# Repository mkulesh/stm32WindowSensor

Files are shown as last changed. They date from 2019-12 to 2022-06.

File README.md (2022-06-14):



# stm32WindowSensor

*RF window sensors: STM32L + RFM69 + Android*

This is a DIY windows monitorig system that consist of:
- A window sensor based on STM32L051 MCU and RFM69 RF module. The PCB is developed in EagleCad, firmware written in C++ using System Workbench for STM32
- A server unit also based on STM32L051 MCU and RFM69 RF module
- A server software module (Java) that reads data from server unit and forwards it to the mobile app
- A mobile app for Android written in Java

## Window Sensor
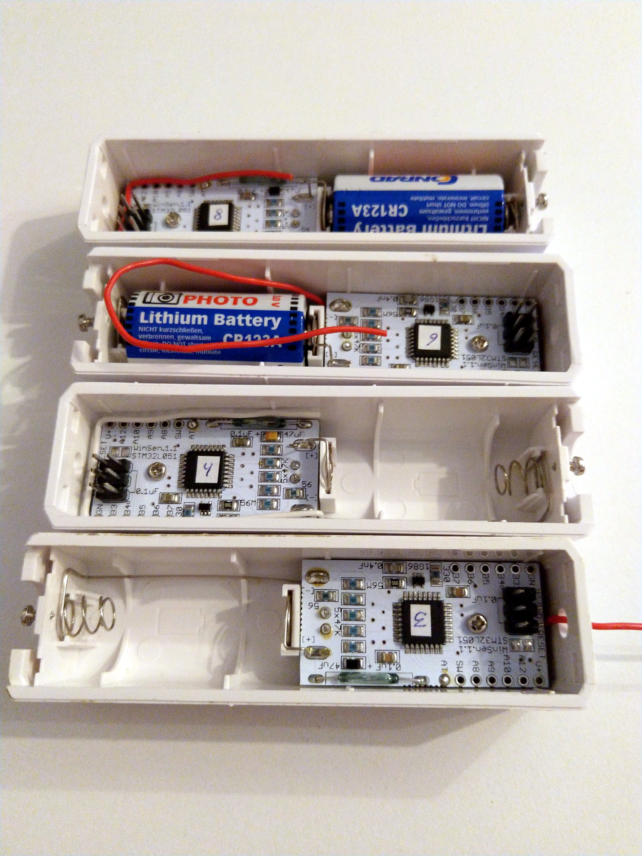
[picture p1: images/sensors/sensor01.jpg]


## Server Unit


## Android App
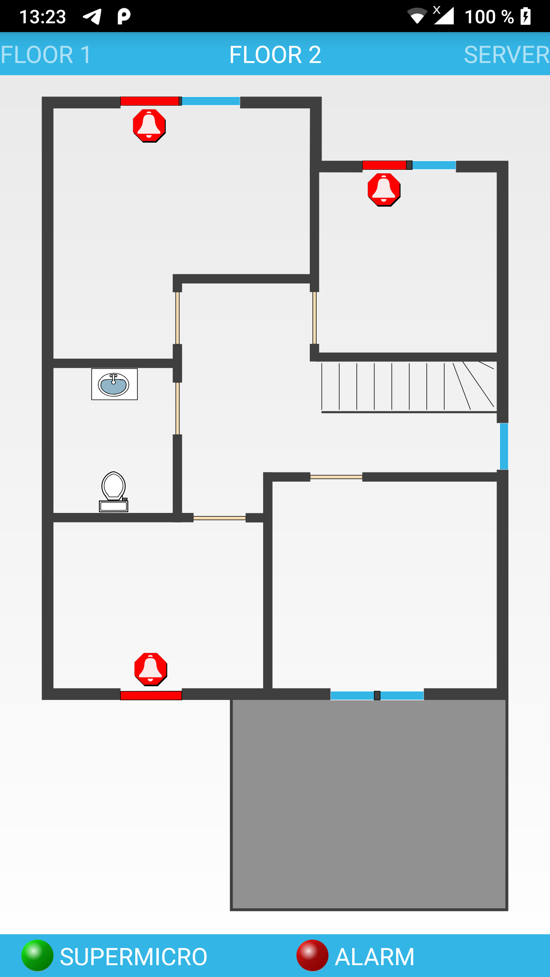
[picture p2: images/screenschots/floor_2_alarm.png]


## License

This software is published under the *GNU General Public License, Version 3*

Copyright © 2018-2019 by Mikhail Kulesh

This program is free software: you can redistribute it and/or modify it under the terms of the GNU General Public License as
published by the Free Software Foundation, either version 3 of the License, or (at your option) any later version.

This program is distributed in the hope that it will be useful, but WITHOUT ANY WARRANTY; without even the implied warranty
of MERCHANTABILITY or FITNESS FOR A PARTICULAR PURPOSE.  See the GNU General Public License for more details. You should have
received a copy of the GNU General Public License along with this program.

If not, see [www.gnu.org/licenses](https://www.gnu.org/licenses).

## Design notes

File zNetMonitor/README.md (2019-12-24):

How to build and install server module and Android app:

1. On the build host:
- Install and setup AndroidStudio, import zNetMonitor project
- In the terminal, go to zNetMonitor directory and enter 

> ./gradlew buildServer

- File znet-server-X.X.jar appears in the _release_ directory. 
- Build the app from AndroidStudio
- File znet-monitor-1.1-release.apk appears in the _release_ directory
- Attach Android device via USB and install the app

> adb install release/znet-monitor-1.1-release.apk

2. On the CentOS 7 server:
- Ensure that the "FT232 Serial" exists and loaded:

> lsusb

> Bus 001 Device 091: ID 0403:6001 Future Technology Devices International, Ltd FT232 Serial (UART) IC

- Add port 5017 fo the firewall:

> firewall-cmd --zone=internal --add-port=5017/tcp --permanent

> firewall-cmd --reload

> firewall-cmd --list-all-zones 
  
- Copy znet ADE (release directory) that includes: znet-server-X.X.jar, znet.cfg, librxtxSerial.so library, startup.sh file
- As root, run startup.sh

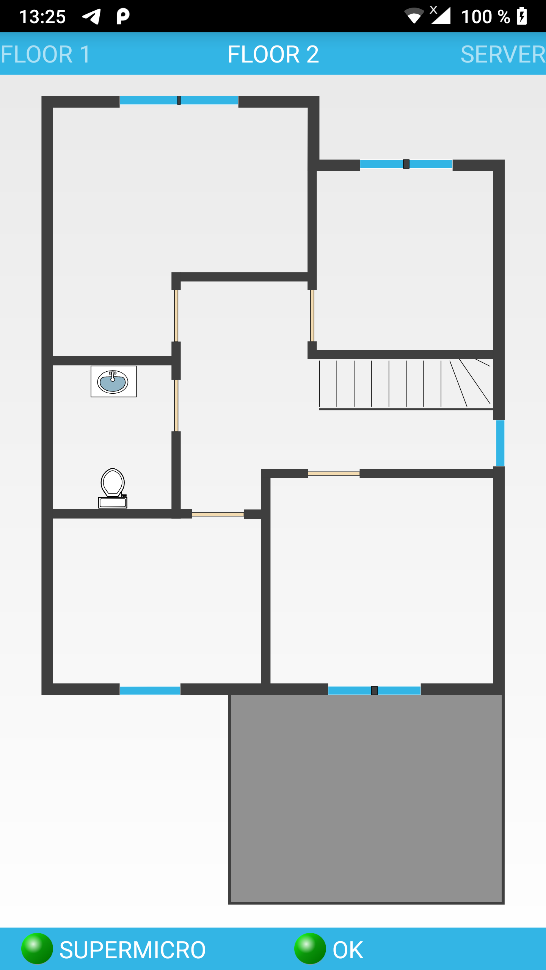
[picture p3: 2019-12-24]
images/screenschots/floor_2_ok.png

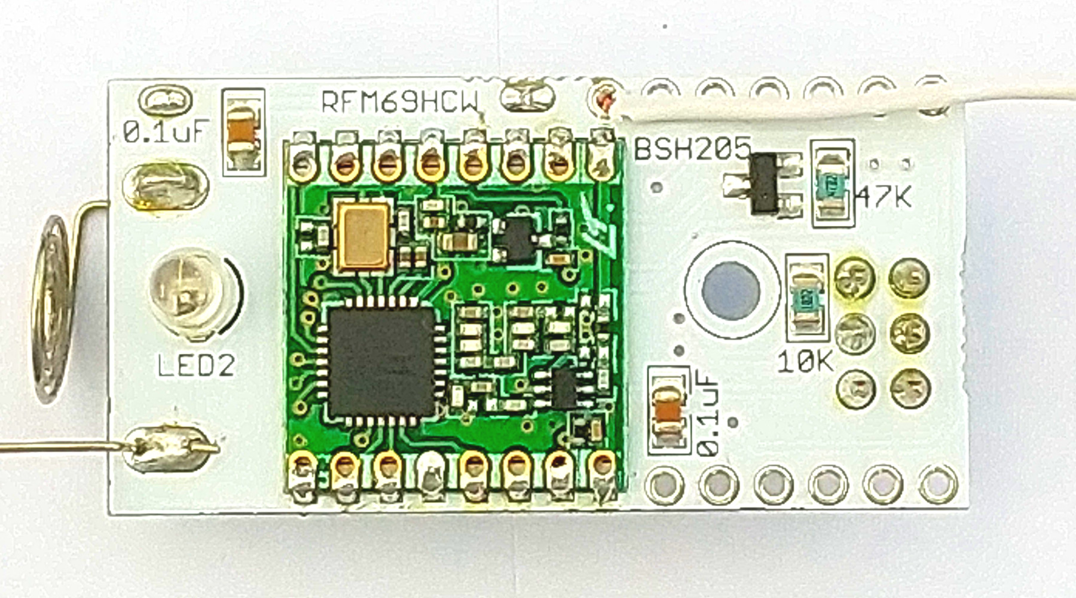
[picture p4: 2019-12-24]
images/sensors/sensor07.jpg

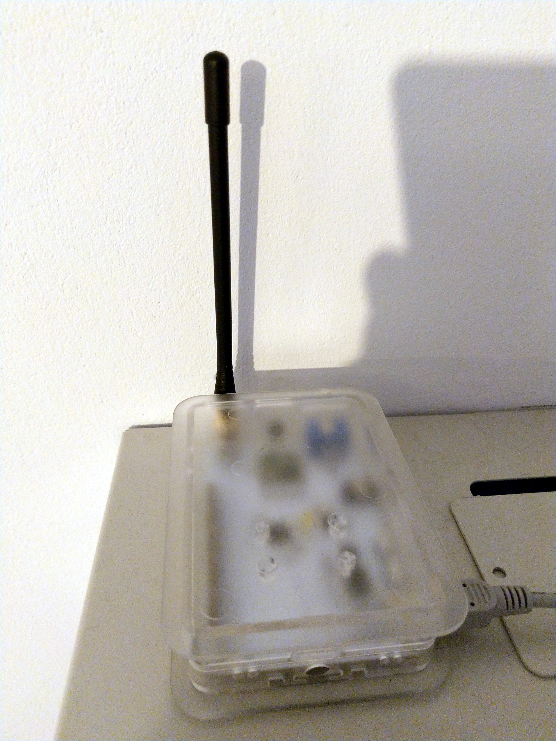
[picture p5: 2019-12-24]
images/server/server02.jpg

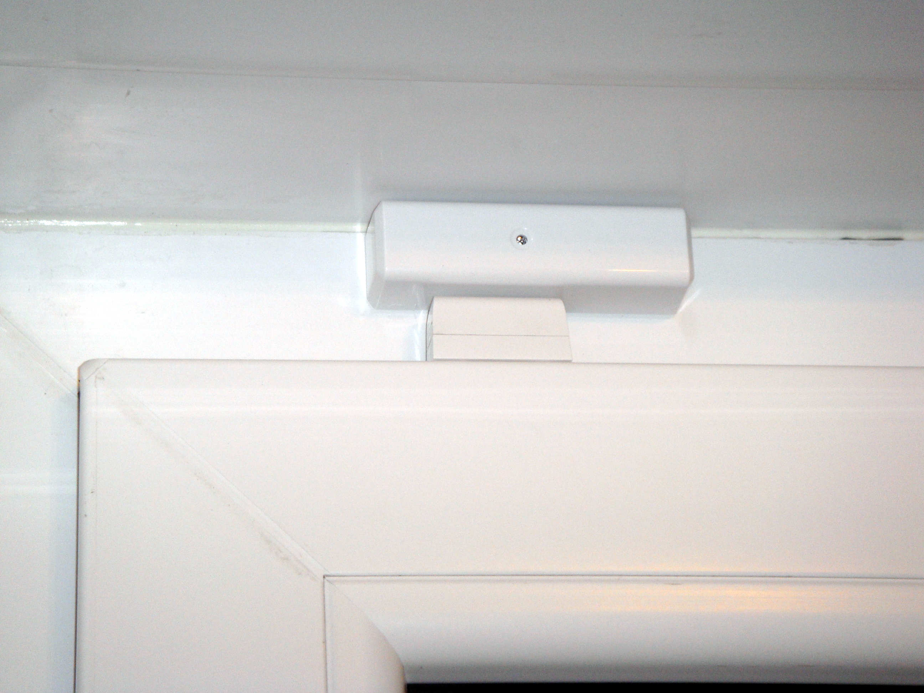
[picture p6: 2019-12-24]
images/sensors/sensor05.jpg

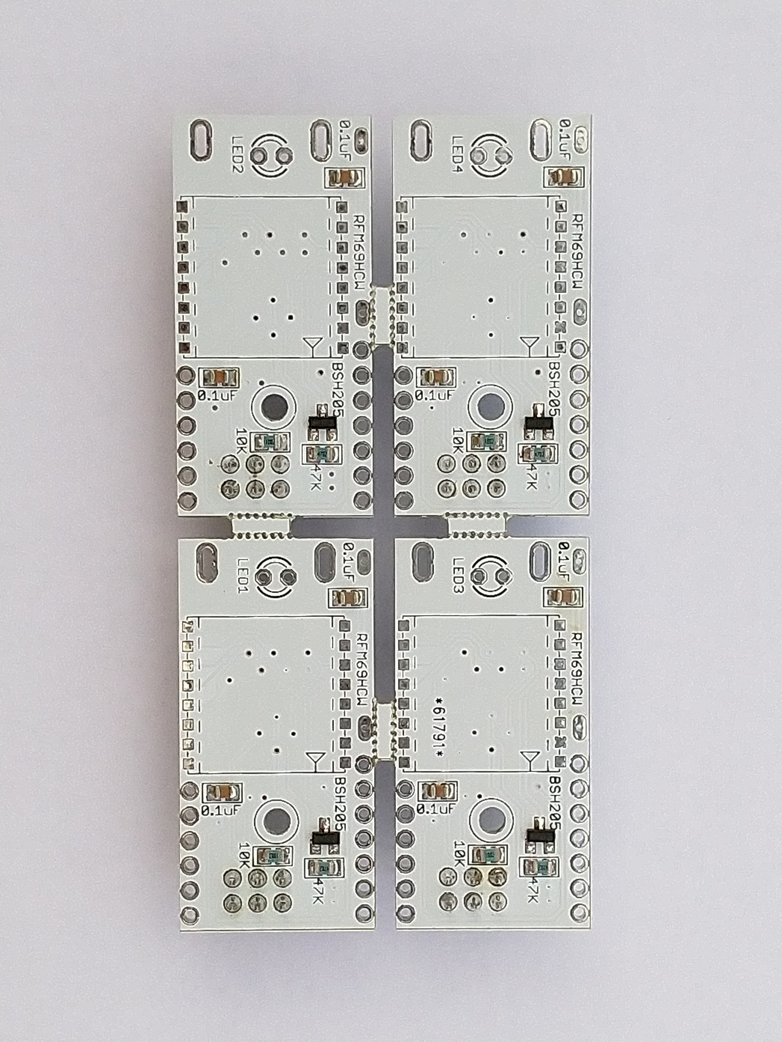
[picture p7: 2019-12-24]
images/pcb/pcb_buttom.jpg

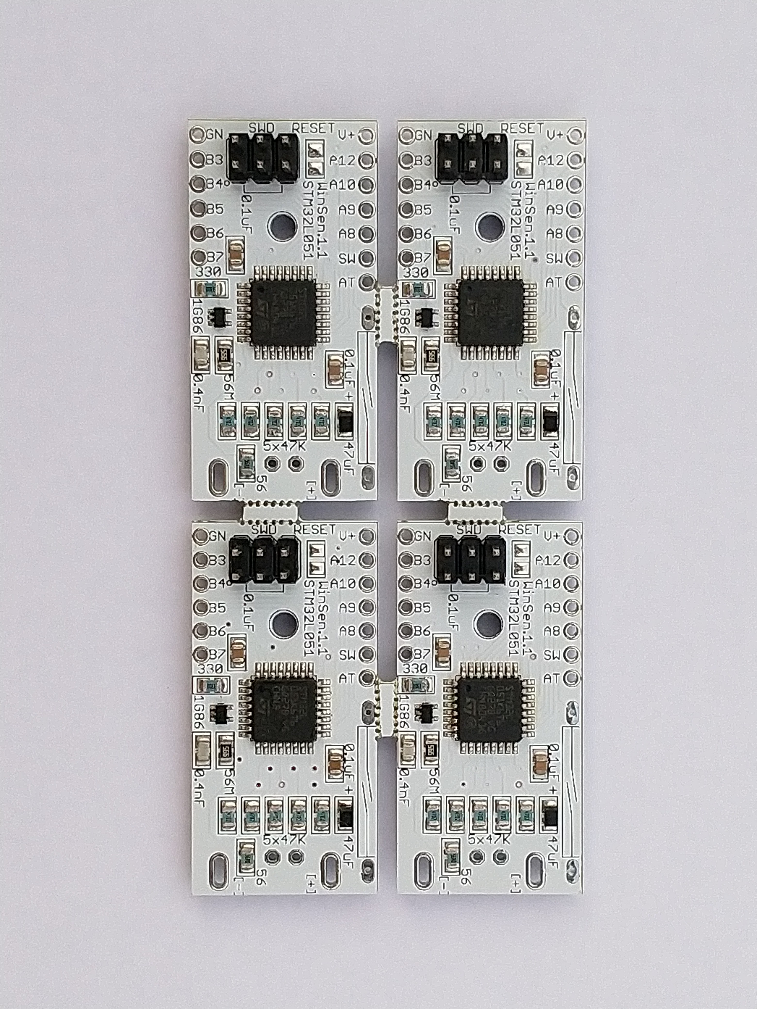
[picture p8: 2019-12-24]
images/pcb/pcb_top.jpg

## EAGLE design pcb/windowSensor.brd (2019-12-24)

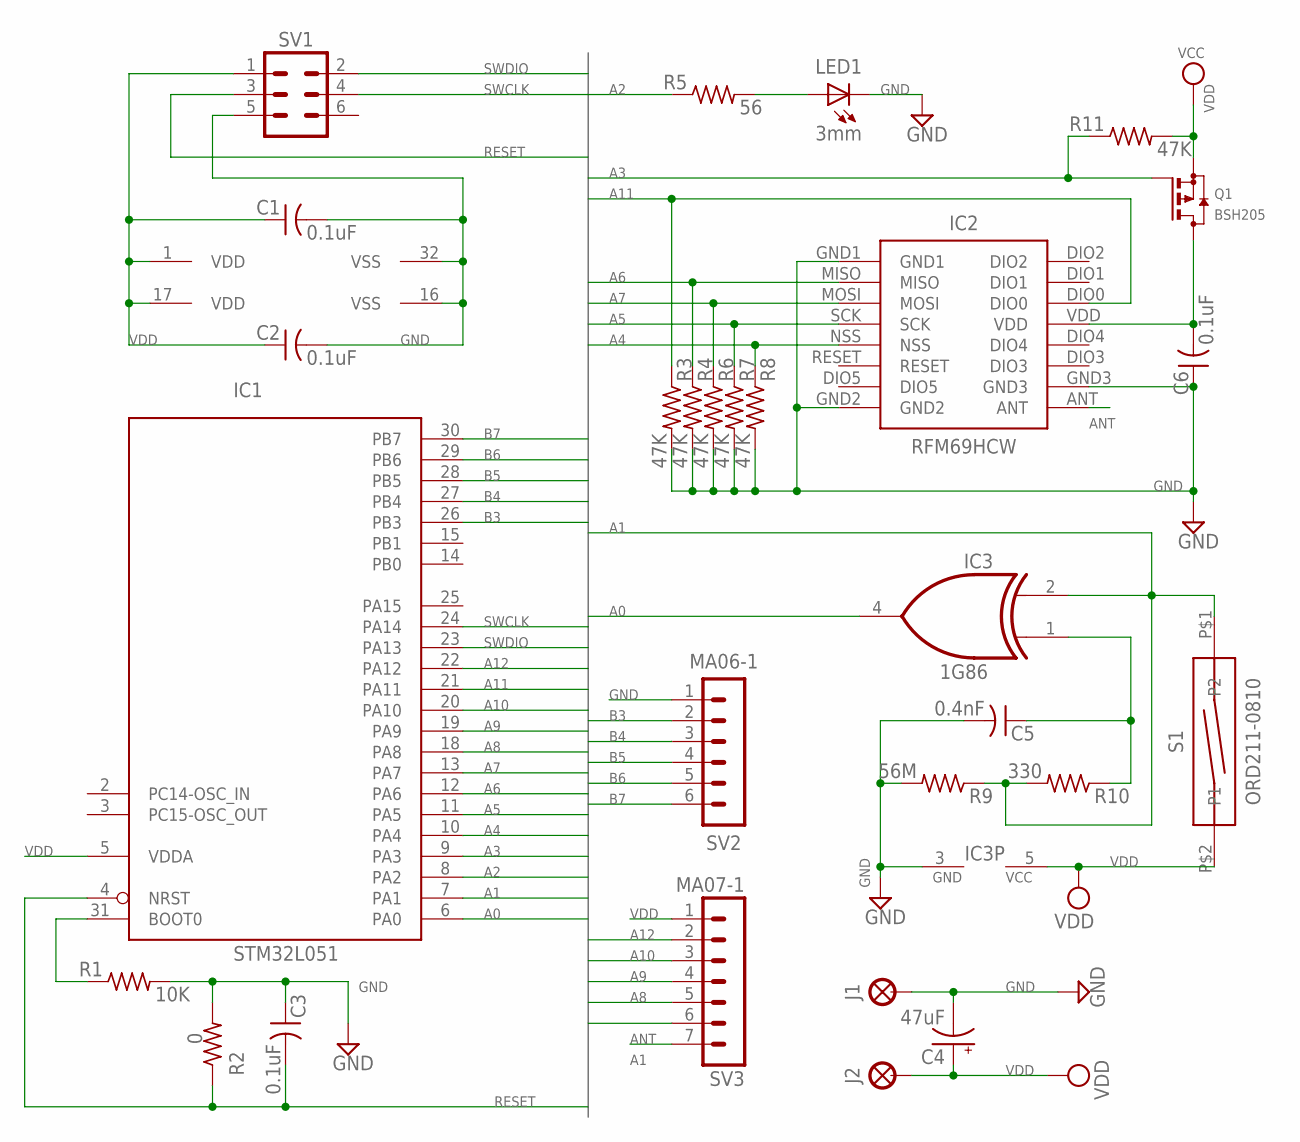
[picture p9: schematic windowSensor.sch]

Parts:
C1, C2, C3, C6: 0.1uF; C0805
C4: 47uF; CPOL0805
C5: 0.4nF; C0805
IC1: STM32L051; LQFP32
IC2: RFM69HCW
IC3: 1G86; SC70-5
J1, J2: LSP30-LONG
LED1: 3mm; LED3MM
Q1: BSH205; SOT23
R1: 10K; R0805
R2: 0; R0805
R3, R4, R6, R7, R8, R11: 47K; R0805
R5: 56; R0805
R9: 56M; R0805
R10: 330; R0805
S1: ORD211-0810
SV1: SWD; MA03-2
SV2: MA06-1; MA06-1-NO-PL
SV3: MA07-1; MA07-1-NO-PL

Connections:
A0: IC1.6 (PA0), IC3.4 (O)
A1: IC1.7 (PA1), IC3.2 (I1), R9.1, R10.2, S1.P$1 (P2), SV3.6
A2: IC1.8 (PA2), R5.1
A3: IC1.9 (PA3), Q1.1 (G), R11.1
A4: IC1.10 (PA4), IC2.NSS, R8.1
A5: IC1.11 (PA5), IC2.SCK, R7.1
A6: IC1.12 (PA6), IC2.MISO, R4.1
A7: IC1.13 (PA7), IC2.MOSI, R6.1
A8: IC1.18 (PA8), SV3.5
A9: IC1.19 (PA9), SV3.4
A10: IC1.20 (PA10), SV3.3
A11: IC1.21 (PA11), IC2.DIO0, R3.1
A12: IC1.22 (PA12), SV3.2
A-BOOT: IC1.31 (BOOT0), R1.1
ANT: IC2.ANT, SV3.7
B3: IC1.26 (PB3), SV2.2
B4: IC1.27 (PB4), SV2.3
B5: IC1.28 (PB5), SV2.4
B6: IC1.29 (PB6), SV2.5
B7: IC1.30 (PB7), SV2.6
GND: C1.2, C2.2, C3.1, C4.2- (-), C5.2, C6.1, IC1.16 (VSS), IC1.32 (VSS), IC2.GND1, IC2.GND2, IC2.GND3, IC3.3 (GND), J1.MP, LED1.K (C), R1.2, R2.2, R3.2, R4.2, R6.2, R7.2, R8.2, R9.2, SV1.5, SV2.1
unnamed: LED1.A, R5.2
unnamed: C5.1, IC3.1 (I0), R10.1
RESET: C3.2, IC1.4 (NRST), R2.1, SV1.3
SD-VDD: C6.2, IC2.VDD, Q1.3 (D)
SWCLK: IC1.24 (PA14), SV1.4
SWDIO: IC1.23 (PA13), SV1.2
VDD: C1.1, C2.1, C4.1+ (+), IC1.1 (VDD), IC1.5 (VDDA), IC1.17 (VDD), IC3.5 (VCC), J2.MP, Q1.2 (S), R11.2, S1.P$2 (P1), SV1.1, SV3.1

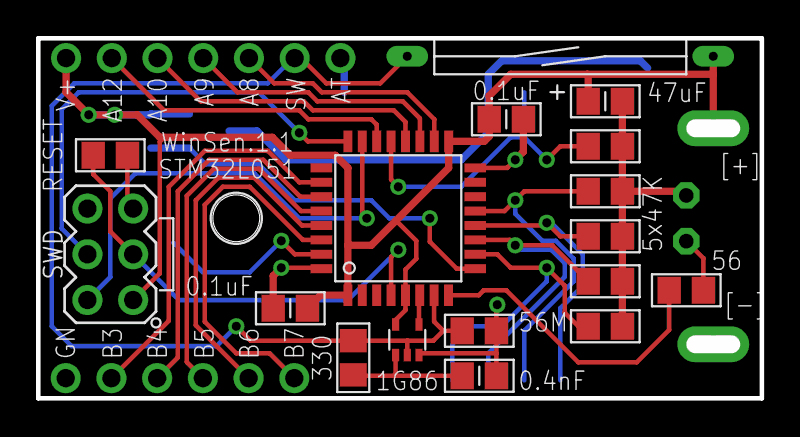
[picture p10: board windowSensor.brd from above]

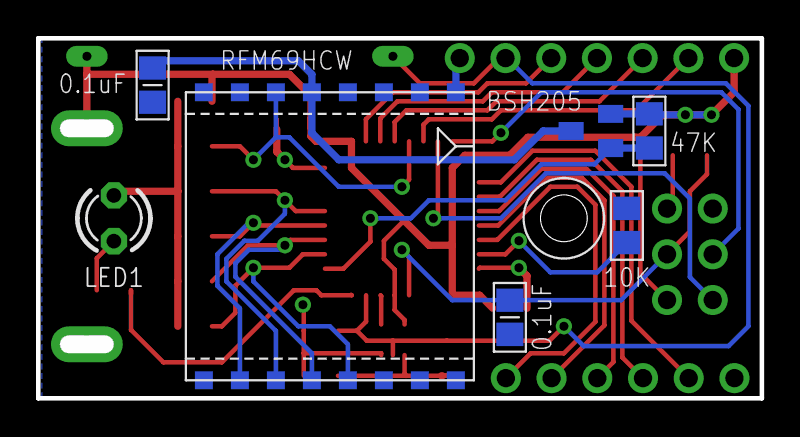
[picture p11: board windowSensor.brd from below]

Board: 2 copper layers, 40.2 x 20.0 mm, 28 parts (7 on the bottom side), 28 nets.

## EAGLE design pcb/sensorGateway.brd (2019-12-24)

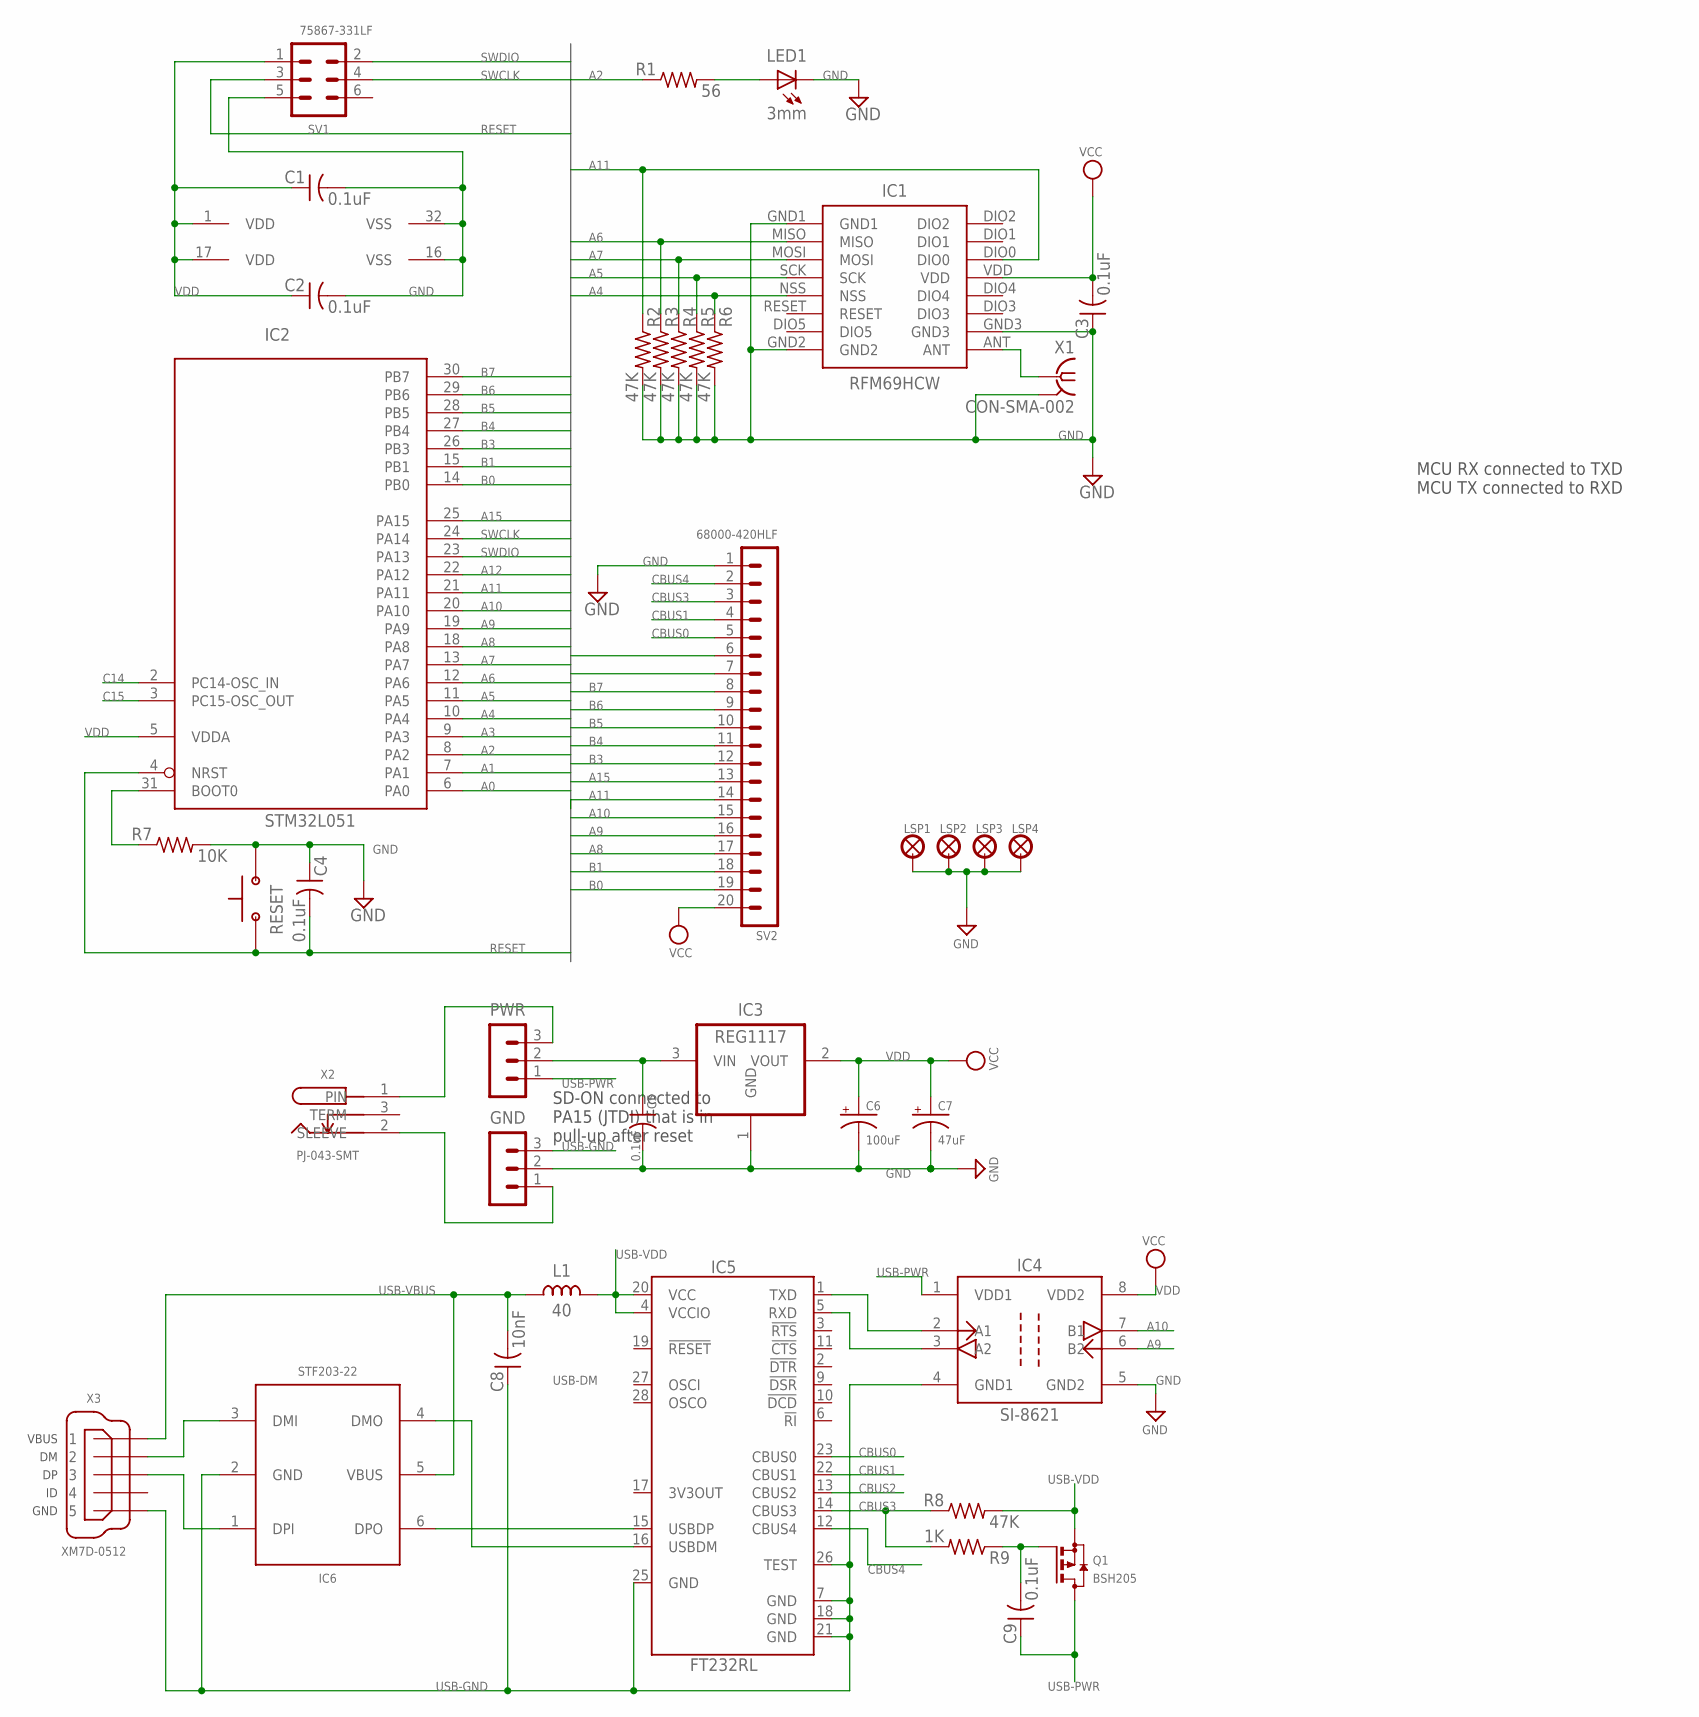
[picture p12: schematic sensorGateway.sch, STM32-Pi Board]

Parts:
C1, C2, C3, C4, C5, C9: 0.1uF; C0805
C6: 100uF; CPOL1311
C7: 47uF; CPOL0805
C8: 10nF; C0805
GND: MA03-1PL; MA03-1
IC1: RFM69HCW
IC2: STM32L051; LQFP32
IC3: REG1117; SOT223
IC4: SI-8621; SOIC-8
IC5: FT232RL; SSOP28
IC6: STF203-22; SC70-6
L1: 40; L0805
LED1: 3mm; LED3MM
LSP1, LSP2, LSP3, LSP4: LSP27
PWR: MA03-1PL; MA03-1
Q1: BSH205; SOT23
R1: 56; R0805
R2, R3, R4, R5, R6, R8: 47K; R0805
R7: 10K; R0805
R9: 1K; R0805
RESET: BUTTON-FSM14JRT
SV1: 75867-331LF; MA03-2
SV2: 68000-420HLF; MA20-1-NO-PL
X1: CON-SMA-002; BU-SMA-G
X2: PJ-043-SMT; BUCHSE-1.0X3.2
X3: XM7D-0512

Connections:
A0: IC2.6 (PA0)
A1: IC2.7 (PA1)
A2: IC2.8 (PA2), R1.1
A3: IC2.9 (PA3)
A4: IC1.NSS, IC2.10 (PA4), R6.1
A5: IC1.SCK, IC2.11 (PA5), R5.1
A6: IC1.MISO, IC2.12 (PA6), R3.1
A7: IC1.MOSI, IC2.13 (PA7), R4.1
A8: IC2.18 (PA8), SV2.17
A9: IC2.19 (PA9), IC4.6 (B2), SV2.16
A10: IC2.20 (PA10), IC4.7 (B1), SV2.15
A11: IC1.DIO0, IC2.21 (PA11), R2.1, SV2.14
A12: IC2.22 (PA12)
A15: IC2.25 (PA15), SV2.13
A-BOOT: IC2.31 (BOOT0), R7.1
B0: IC2.14 (PB0), SV2.19
B1: IC2.15 (PB1), SV2.18
B3: IC2.26 (PB3), SV2.12
B4: IC2.27 (PB4), SV2.11
B5: IC2.28 (PB5), SV2.10
B6: IC2.29 (PB6), SV2.9
B7: IC2.30 (PB7), SV2.8
C14: IC2.2 (PC14-OSC_IN), SV2.7
C15: IC2.3 (PC15-OSC_OUT), SV2.6
CBUS0: IC5.23 (CBUS0), SV2.5
CBUS1: IC5.22 (CBUS1), SV2.4
CBUS2: IC5.13 (CBUS2)
CBUS3: IC5.14 (CBUS3), R8.1, R9.2, SV2.3
CBUS4: IC5.12 (CBUS4), SV2.2
GND: C1.2, C2.2, C3.1, C4.1, C5.2, C6.2- (-), C7.2- (-), GND.2, IC1.GND1, IC1.GND2, IC1.GND3, IC2.16 (VSS), IC2.32 (VSS), IC3.1 (GND), IC4.5 (GND2), LED1.K (C), LSP1.MP, LSP2.MP, LSP3.MP, LSP4.MP, R2.2, R3.2, R4.2, R5.2, R6.2, R7.2, RESET.P$2 (2), SV1.5, SV2.1, X1.2, X1.3 (2), X1.4 (2), X1.5 (2)
unnamed: LED1.A, R1.2
unnamed: IC1.ANT, X1.1
unnamed: C9.2, Q1.1 (G), R9.1
unnamed: IC4.2 (A1), IC5.1 (TXD)
unnamed: GND.1, X2.2 (SLEEVE)
unnamed: IC4.3 (A2), IC5.5 (RXD)
unnamed: PWR.3, X2.1 (PIN)
unnamed: IC6.1 (DPI), X3.3
unnamed: IC6.3 (DMI), X3.2
RESET: C4.2, IC2.4 (NRST), RESET.P$1 (1), SV1.3
SWCLK: IC2.24 (PA14), SV1.4
SWDIO: IC2.23 (PA13), SV1.2
USB-DM: IC5.16 (USBDM), IC6.4 (DMO)
USB-DP: IC5.15 (USBDP), IC6.6 (DPO)
USB-GND: C8.1, GND.3, IC4.4 (GND1), IC5.7 (GND), IC5.18 (GND), IC5.21 (GND), IC5.25 (GND), IC5.26 (TEST), IC6.2 (GND), X3.5
USB-PWR: C9.1, IC4.1 (VDD1), PWR.1, Q1.3 (D)
USB-VBUS: C8.2, IC6.5 (VBUS), L1.1, X3.1
USB-VDD: IC5.4 (VCCIO), IC5.20 (VCC), L1.2, Q1.2 (S), R8.2
VDD: C1.1, C2.1, C3.2, C6.1+ (+), C7.1+ (+), IC1.VDD, IC2.1 (VDD), IC2.5 (VDDA), IC2.17 (VDD), IC3.2 (VOUT), IC4.8 (VDD2), SV1.1, SV2.20
VIN: C5.1, IC3.3 (VIN), PWR.2

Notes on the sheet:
SD-ON connected to PA15 (JTDI) that is in pull-up after reset
MCU RX connected to TXD MCU TX connected to RXD

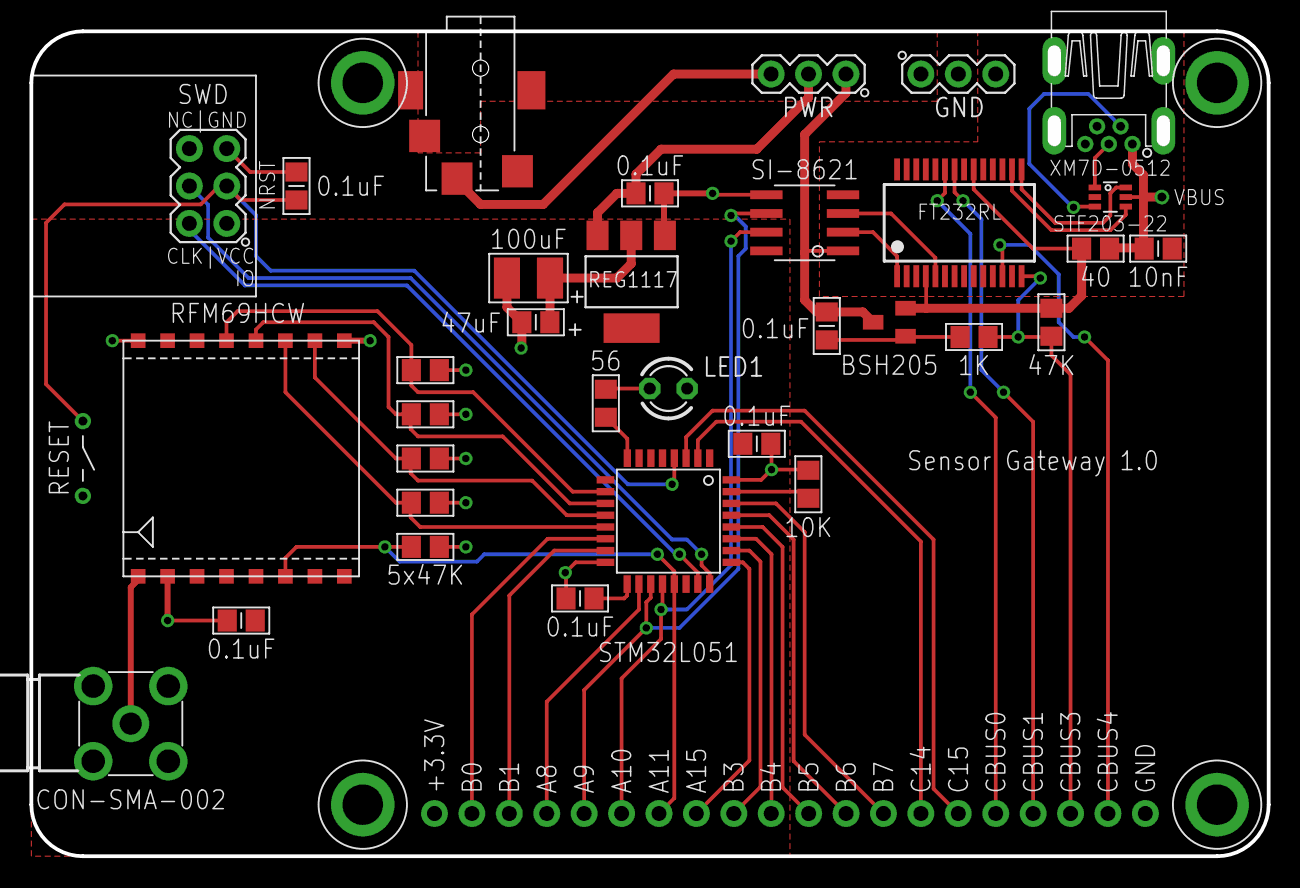
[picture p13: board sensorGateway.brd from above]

Board: 2 copper layers, 84.0 x 56.0 mm, 39 parts (0 on the bottom side), 45 nets.

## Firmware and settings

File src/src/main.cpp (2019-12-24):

/*
 * stm32WindowSensor: RF window sensors: STM32L + RFM69 + Android
 *
 * Copyright (C) 2019. Mikhail Kulesh
 *
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
 * This program is distributed in the hope that it will be useful, but WITHOUT ANY WARRANTY; without
 * even the implied warranty of MERCHANTABILITY or FITNESS FOR A PARTICULAR PURPOSE. See the
 * GNU General Public License for more details. You should have received a copy of the GNU General
 * Public License along with this program.
 */

#define SENSOR_LOGIC true

#include "WindowSensor.h"
#include "SensorGateway.h"

__IO uint32_t sysTick;

SensorBase * appPtr = NULL;

int main (void)
{
    HAL_Init();

    IOPort defaultPortA(IOPort::PortName::A, GPIO_MODE_ANALOG, GPIO_NOPULL, GPIO_SPEED_LOW); __GPIOA_CLK_DISABLE();
    IOPort defaultPortB(IOPort::PortName::B, GPIO_MODE_ANALOG, GPIO_NOPULL, GPIO_SPEED_LOW); __GPIOB_CLK_DISABLE();
    IOPort defaultPortC(IOPort::PortName::C, GPIO_MODE_ANALOG, GPIO_NOPULL, GPIO_SPEED_LOW); __GPIOC_CLK_DISABLE();

#ifdef SENSOR_LOGIC
    WindowSensor::initSystemClock();
    WindowSensor::initWakeUp();
    WindowSensor sensor(/*sensorId=*/ 19);
    appPtr = &sensor;
    sensor.run();
#else
    SensorGateway::initSystemClock();
    SensorGateway::initWakeUp();
    SensorGateway gateway;
    appPtr = &gateway;
    gateway.run();
#endif

    while (true)
    {
        // empty
    }
}

extern "C" void EXTI0_1_IRQHandler (void)
{
    appPtr->processEXTI0_1_IRQn();
}

extern "C" void HAL_SYSTICK_Callback (void)
{
    ++sysTick;
}

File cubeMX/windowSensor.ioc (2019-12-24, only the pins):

Mcu.UserName=STM32L051K8Tx
PA0.Signal=SYS_WKUP1
PA1.GPIO_Label=pinSwithValue
PA1.Signal=GPIO_Input
PA10.Signal=USART1_RX
PA11.GPIO_Label=pinDio0
PA11.Signal=GPIO_Input
PA13.Signal=SYS_SWDIO
PA14.Signal=SYS_SWCLK
PA2.GPIO_Label=pinLed
PA2.Signal=S_TIM2_CH3
PA3.GPIO_Label=pinRfmPower
PA3.Signal=GPIO_Output
PA4.Signal=SPI1_NSS
PA5.Signal=SPI1_SCK
PA6.Signal=SPI1_MISO
PA7.Signal=SPI1_MOSI
PA9.Signal=USART1_TX

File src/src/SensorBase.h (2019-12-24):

/*
 * stm32WindowSensor: RF window sensors: STM32L + RFM69 + Android
 *
 * Copyright (C) 2019. Mikhail Kulesh
 *
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
 * This program is distributed in the hope that it will be useful, but WITHOUT ANY WARRANTY; without
 * even the implied warranty of MERCHANTABILITY or FITNESS FOR A PARTICULAR PURPOSE. See the
 * GNU General Public License for more details. You should have received a copy of the GNU General
 * Public License along with this program.
 */

#ifndef SENSOR_BASE_H_
#define SENSOR_BASE_H_

#include "RFM69.h"

#include <algorithm>
#include <array>

using namespace StmPlusPlus;

class SensorBase
{
public:

    enum DataType
    {
        STARTUP = 1,
        WAIT_FOR_READY = 2,
        ERROR = 3,
        SENSOR_DATA = 4,
        STANDBY = 5
    };

    // SYS_WKUP1 (IOPort::A, GPIO_PIN_0) is used as wakeup trigger
    static const uint16_t PIN_SWITH_VALUE = GPIO_PIN_1;
    static const IRQn_Type EVENT_IRQN = EXTI0_1_IRQn;

    static constexpr uint8_t BASE_ID = 1;
    static constexpr uint8_t PACKET_SIZE = 7;
    static constexpr size_t ADC_BUFFER_LENGTH = 5;
    static constexpr size_t MIN_VOLTAGE = 18;
    static constexpr size_t REPEAT_ON_ERROR_COUNT = 10;
    static constexpr uint32_t REPEAT_ON_ERROR_DELAY = 1000;

    // Magnetic switch
    __IO uint32_t switchChanges;

    // Voltage
    AnalogToDigitConverter adc;

    // RFM69 on SPI
    IOPin pinRfmPower, pinRfmCs, pinRfmDio0;
    Spi spi;
    RFM69 rfm;

    // LEDs
    PulseWidthModulation pinLed;

    SensorBase () :
        switchChanges(1),

        // Voltage
        adc(ADC_CHANNEL_VREFINT),

        // RFM69 on SPI
        pinRfmPower(IOPort::A, GPIO_PIN_3, GPIO_MODE_OUTPUT_PP, GPIO_NOPULL, GPIO_SPEED_FREQ_LOW, true, true),
        pinRfmCs(IOPort::A, GPIO_PIN_4, GPIO_MODE_OUTPUT_PP, GPIO_NOPULL, GPIO_SPEED_FREQ_LOW, true, false),
        pinRfmDio0(IOPort::A, GPIO_PIN_11, GPIO_MODE_INPUT, GPIO_NOPULL, GPIO_SPEED_FREQ_LOW),
        spi(Spi::SPI_1, /*SCK*/ IOPort::A, GPIO_PIN_5,
                        /* MI*/ IOPort::A, GPIO_PIN_6,
                        /* MO*/ IOPort::A, GPIO_PIN_7,
                        GPIO_NOPULL, GPIO_SPEED_FREQ_LOW),
        rfm(spi, pinRfmCs, pinRfmDio0),

        // LEDs
        pinLed(IOPort::A, GPIO_PIN_2, GPIO_SPEED_FREQ_LOW, TimerBase::TIM_2, TIM_CHANNEL_3)
    {
        // Activate interrupts for magnetic switch and busy line
        HAL_NVIC_SetPriority(EVENT_IRQN, 1, 0);
        HAL_NVIC_EnableIRQ(EVENT_IRQN);
    }

    /*
     * Wake Up configuration.
     */
    static void initWakeUp (void)
    {
        // Enable Ultra low power mode
        HAL_PWREx_EnableUltraLowPower();

        // Enable the fast wake up from Ultra low power mode
        HAL_PWREx_EnableFastWakeUp();

        // Check and handle if the system was resumed from Standby mode
        if (__HAL_PWR_GET_FLAG(PWR_FLAG_SB) != RESET)
        {
            // Clear Standby flag
            __HAL_PWR_CLEAR_FLAG(PWR_FLAG_SB);
        }

        // Disable all used wakeup sources: Pin1(PA.0)
        HAL_PWR_DisableWakeUpPin(PWR_WAKEUP_PIN1);

        // Clear all related wakeup flags
        __HAL_PWR_CLEAR_FLAG(PWR_FLAG_WU);
    }

    void processEXTI0_1_IRQn ()
    {
        if (__HAL_GPIO_EXTI_GET_FLAG(PIN_SWITH_VALUE))
        {
            ++switchChanges;
        }
        HAL_GPIO_EXTI_IRQHandler(PIN_SWITH_VALUE);
    }

    uint8_t CRC7_one(uint8_t crcIn, uint8_t data)
    {
        const uint8_t g = 0x89;
        uint8_t i;
        crcIn ^= data;
        for (i = 0; i < 8; i++)
        {
            if (crcIn & 0x80)
                crcIn ^= g;
            crcIn <<= 1;
        }
        return crcIn;
    }

    uint8_t CRC7_buf(uint8_t *pBuf, uint8_t len)
    {
        uint8_t crc = 0;
        while (len--)
            crc = CRC7_one(crc, *pBuf++);
        return crc;
    }

    uint8_t getMedianVoltage ()
    {
        std::array<uint32_t, ADC_BUFFER_LENGTH> adcBuffer;
        adcBuffer.fill(0);

        for (size_t i = 0; i < ADC_BUFFER_LENGTH; ++i)
        {
            if (adc.start() == HAL_OK)
            {
                adcBuffer[i] = adc.getValue();
            }
            adc.stop();
        }

        std::sort(adcBuffer.begin(), adcBuffer.end());
        float m = adcBuffer[ADC_BUFFER_LENGTH/2];
        return (uint8_t)(29.0 * 1820.0 / m);
    }

    uint32_t getLedPwm (uint8_t vdd)
    {
        uint32_t pwmMv = std::min(std::max((uint32_t)vdd, (uint32_t)18), (uint32_t)30);
        uint32_t pwm = 10 + 90 * (30 - pwmMv) / (30 - 18);
        return pwm;
    }

    void stopRfm()
    {
        pinRfmPower.setHigh();
        pinRfmCs.setLow();
        spi.stop();
    }

    bool initRfm (uint8_t id, uint32_t pwm)
    {
        for (size_t i = 0; i < REPEAT_ON_ERROR_COUNT; i++)
        {
            pinRfmCs.setHigh();
            pinRfmPower.setLow();
            spi.start(SPI_DIRECTION_2LINES, SPI_BAUDRATEPRESCALER_4, SPI_DATASIZE_8BIT, SPI_PHASE_2EDGE);
            if (rfm.initialize(RF69_433MHZ, id, 1))
            {
                rfm.setHighPower(true);
                return true;
            }
            else
            {
                pinLed.start(100, pwm);
                stopRfm();
                HAL_Delay(REPEAT_ON_ERROR_DELAY);
                pinLed.stop();
            }
        }
        return false;
    }

    void enterStandBy (bool _stopRfm = true)
    {
        // The Following Wakeup sequence is highly recommended prior to each Standby mode entry
        //   mainly  when using more than one wakeup source this is to not miss any wakeup event.
        //   - Disable all used wakeup sources,
        //   - Clear all related wakeup flags,
        //  - Re-enable all used wakeup sources,
        //   - Enter the Standby mode
        if (_stopRfm)
        {
            stopRfm();
        }

        HAL_PWR_EnableWakeUpPin(PWR_WAKEUP_PIN1);
        HAL_PWR_EnterSTANDBYMode();
    }
};


#endif

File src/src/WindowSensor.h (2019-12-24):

/*
 * stm32WindowSensor: RF window sensors: STM32L + RFM69 + Android
 *
 * Copyright (C) 2019. Mikhail Kulesh
 *
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
 * This program is distributed in the hope that it will be useful, but WITHOUT ANY WARRANTY; without
 * even the implied warranty of MERCHANTABILITY or FITNESS FOR A PARTICULAR PURPOSE. See the
 * GNU General Public License for more details. You should have received a copy of the GNU General
 * Public License along with this program.
 */

#ifndef WINDOW_SENSOR_H_
#define WINDOW_SENSOR_H_

#ifdef SENSOR_LOGIC

#include "SensorBase.h"
#include "EepRomInteger.h"

using namespace StmPlusPlus;

#define USART_DEBUG_MODULE "WS;"

class WindowSensor : public SensorBase
{
private:
    
    // Sensor ID
    uint8_t sensorId;

    // Magnetic switch
    IOPin pinSwithValue;

    // Last reported data sensor state
    EepRomInteger lastReportedRequestId, lastReportedSensorState;

    // Data packet
    uint8_t packet[PACKET_SIZE];
    RFM69::Payload response;

    // Logging
    UsartLogger log;
    uint32_t startTime;

public:
    
    WindowSensor (uint8_t _sensorId) :
        SensorBase(),

        // Sensor ID
        sensorId(_sensorId),

        // Magnetic switch
        pinSwithValue(IOPort::A, PIN_SWITH_VALUE, GPIO_MODE_IT_RISING_FALLING, GPIO_PULLDOWN, GPIO_SPEED_FREQ_LOW),

        // Last reported sensor state
        lastReportedRequestId(0),
        lastReportedSensorState(4),

        // Logging
        log(Usart::USART_1, IOPort::A, GPIO_PIN_9, GPIO_PIN_10, GPIO_SPEED_FREQ_LOW, 19200),
        startTime(HAL_GetTick())
    {
        // empty
    }
    
    static void initSystemClock (void)
    {
        RCC_OscInitTypeDef RCC_OscInitStruct;
        RCC_ClkInitTypeDef RCC_ClkInitStruct;
        
        __HAL_RCC_PWR_CLK_ENABLE();
        __HAL_PWR_VOLTAGESCALING_CONFIG(PWR_REGULATOR_VOLTAGE_SCALE3);
        
        RCC_OscInitStruct.OscillatorType = RCC_OSCILLATORTYPE_MSI;
        RCC_OscInitStruct.MSIState = RCC_MSI_ON;
        RCC_OscInitStruct.MSICalibrationValue = 0;
        RCC_OscInitStruct.MSIClockRange = RCC_MSIRANGE_4;
        RCC_OscInitStruct.PLL.PLLState = RCC_PLL_NONE;
        HAL_RCC_OscConfig(&RCC_OscInitStruct);
        
        RCC_ClkInitStruct.ClockType = RCC_CLOCKTYPE_HCLK|RCC_CLOCKTYPE_SYSCLK
                                    |RCC_CLOCKTYPE_PCLK1|RCC_CLOCKTYPE_PCLK2;
        RCC_ClkInitStruct.SYSCLKSource = RCC_SYSCLKSOURCE_MSI;
        RCC_ClkInitStruct.AHBCLKDivider = RCC_SYSCLK_DIV1;
        RCC_ClkInitStruct.APB1CLKDivider = RCC_HCLK_DIV1;
        RCC_ClkInitStruct.APB2CLKDivider = RCC_HCLK_DIV1;
        HAL_RCC_ClockConfig(&RCC_ClkInitStruct, FLASH_LATENCY_1);
        
        RCC_PeriphCLKInitTypeDef PeriphClkInit;
        PeriphClkInit.PeriphClockSelection = RCC_PERIPHCLK_USART1;
        PeriphClkInit.Usart1ClockSelection = RCC_USART1CLKSOURCE_SYSCLK;
        HAL_RCCEx_PeriphCLKConfig(&PeriphClkInit);
        
        HAL_SYSTICK_Config(HAL_RCC_GetHCLKFreq() / 1000);
        HAL_SYSTICK_CLKSourceConfig(SYSTICK_CLKSOURCE_HCLK);
        HAL_NVIC_SetPriority(SysTick_IRQn, 0, 0);
    }
    
    void run ()
    {
        //log.initInstance();

        uint8_t vdd = getMedianVoltage();
        uint32_t pwm = getLedPwm(vdd);

        //USART_DEBUG((int)DataType::STARTUP << ";" << SystemCoreClock << ";" << vdd << ";" << (HAL_GetTick() - startTime) << "ms.");
        if (vdd < MIN_VOLTAGE)
        {
            USART_DEBUG((int)DataType::ERROR << ";" << sensorId << ";Low voltage");
            enterStandBy(false);
        }

        rfm.setSpiDelay(1);
        if (!initRfm(sensorId, pwm))
        {
            USART_DEBUG((int)DataType::ERROR << ";" << sensorId << ";Can not initialize RFM.");
            enterStandBy();
        }

        waitForTransmit();
        //USART_DEBUG((int)DataType::WAIT_FOR_READY << ";" << sensorId << ";" << (HAL_GetTick() - startTime) << "ms.");

        reportSensor(vdd, pwm);

        //USART_DEBUG((int)DataType::STANDBY << ";" << sensorId << ";" << (HAL_GetTick() - startTime) << "ms.");
        //HAL_Delay(20);
        
        enterStandBy();
    }
    
    void waitForTransmit()
    {
        uint32_t delay = 5 * sensorId;
        rfm.receiveBegin();
        uint32_t receiveTime = HAL_GetTick();
        do
        {
            int16_t rssi = rfm.readRSSI(false);
            if (rssi > CSMA_LIMIT)
            {
                receiveTime = HAL_GetTick();
            }
            if (pinRfmDio0.getBit() && rfm.readData(response))
            {
                receiveTime = HAL_GetTick();
            }
        }
        while(HAL_GetTick() - receiveTime <= delay);
    }

    void reportSensor (uint8_t vdd, uint32_t pwm)
    {
        uint32_t reqId = lastReportedRequestId.readValue();
        while (switchChanges > 0)
        {
            reqId++;
            bool reportedValue = pinSwithValue.getBit();
            switchChanges = 0;
            if (sendSensorState(reqId, reportedValue, vdd, pwm))
            {
                if (lastReportedRequestId.writeValue(reqId) != HAL_OK)
                {
                    USART_DEBUG((int)DataType::ERROR << ";" << sensorId << ";Can not store request ID in EEPROM");
                }
            }
        }
    }

    bool sendSensorState (uint16_t reqId, uint8_t sensorState, uint8_t vdd, uint32_t pwm)
    {
        bool retValue = false;

        WordToBytes w;
        w.word = reqId;

        packet[0] = sensorState;
        packet[1] = w.bytes.low;
        packet[2] = w.bytes.high;
        packet[3] = vdd;
        packet[4] = rfm.readTemperature(0);
        packet[5] = CRC7_buf(packet, PACKET_SIZE - 2);
        packet[6] = 0xFF;

        uint16_t respId = 0;
        for (size_t i = 0; i < REPEAT_ON_ERROR_COUNT; i++)
        {
            pinLed.start(100, pwm);
            rfm.send(BASE_ID, packet, PACKET_SIZE, /*requestACK=*/ true);
            pinLed.stop();
            if (rfm.waitForResponce(pinRfmDio0, response, 100))
            {
                w.bytes.low = response.data[1];
                w.bytes.high = response.data[2];
                respId = w.word;
                if (response.senderId == BASE_ID &&
                    response.targetId == sensorId &&
                    response.ackReceiver() &&
                    respId == reqId)
                {
                    retValue = true;
                    break;
                }
            }
        }

        USART_DEBUG((int)DataType::SENSOR_DATA
                    << ";" << sensorId
                    << ";" << response.signalStrength
                    << ";" << packet[0]
                    << ";" << reqId
                    << ";" << packet[3]
                    << ";" << packet[4]
                    << ";" << (HAL_GetTick() - startTime) << "ms.");

        return retValue;
    }

};

#endif
#endif

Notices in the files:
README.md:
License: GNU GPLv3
